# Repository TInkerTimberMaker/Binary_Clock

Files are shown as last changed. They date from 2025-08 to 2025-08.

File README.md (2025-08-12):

# Arduino Binary Clock (3× 74HC595 + DS3231)

A friendly, buildable binary‑coded decimal (BCD) clock for the Arduino Nano. It drives **three chained 74HC595 shift registers** in **sink mode** to show **hours, minutes, seconds**. A **DS3231 RTC** provides accurate timekeeping; two buttons set the time; a pot on **A1** controls global brightness via PWM on **D6**.

---
## Features
- **Time display**: Shows hours (00–23), minutes (00–59), seconds (00–59)
- **Accurate time** via DS3231 RTC (±2 ppm typical)
- **Packed BCD display**: tens and ones shown separately for Hours, Minutes, and Seconds
- **Brightness knob**: analog pot (A1) → PWM on OĒ (D6)
- **Set time**: Two buttons increment **minutes (D4)** and **hours (D3)**
- **Startup animation** if the RTC reports lost power (until a button press)
- **Low overhead**: loop updates only when the second changes; prints `HH:MM:SS  — CPU Work: xxxxµs` over Serial @ 9600 baud
- **Serial debug**: Prints `HH:MM:SS` on USB serial at 9600 baud

---
## Hardware Required
- Arduino Nano (or any 5 V Arduino)
- 3 × 74HC595N shift‑register chips
- DS3231 RTC module
- LEDs × 20 (6 hr + 7 min + 7 sec)
- Resistors (~470 Ω) × 20
- 1000µF electrolytic cap
- 2 × momentary pushbuttons
- Breadboard/wiring, Perfboard and hook up wires, or PCB

> **Sink mode** means LED anodes go to **+5 V** through a resistor and the HC595 outputs **pull low** to light the LED. That’s why the sketch inverts the BCD bits.

---
## Wiring

### Arduino ↔ 74HC595 chain

**Chain the data:** Arduino drives the **first** HC595’s SER; then **Q7′ (pin 9)** of each chip feeds the **next** chip’s SER.

| Connection | HC595 #1 | HC595 #2 | HC595 #3 |
| --- | --- | --- | --- |
| **D11 → SER (data)** | Pin 14 | *(from #1 Q7′ pin 9 → #2 SER pin 14)* | *(from #2 Q7′ pin 9 → #3 SER pin 14)* |
| **D12 → SH\_CP (shift clock)** | Pin 11 | Pin 11 | Pin 11 |
| **D8  → ST\_CP (latch)** | Pin 12 | Pin 12 | Pin 12 |
| **D6  → OĒ (PWM brightness)** | Pin 13 | Pin 13 | Pin 13 |
| **+5 V → SRCLR̄** | Pin 10 | Pin 10 | Pin 10 |
| **+5 V / GND** | Pin 16 / Pin 8 | Pin 16 / Pin 8 | Pin 16 / Pin 8 |

> If you don’t need brightness control, you may tie **OĒ (pin 13) to GND**. With dimming, keep OĒ on **D6 (PWM)**.

### RTC (DS3231)

| RTC Pin | Arduino |
| --- | --- |
| VCC | +3.3 V |
| GND | GND |
| SDA | A4 |
| SCL | A5 |
| SQW | *(optional)* D2 (for 1 Hz interrupt; not required in this sketch) |

### LED mapping (sink‑mode)

Each LED: **+5 V → resistor → LED anode → LED cathode → Qx** on the HC595.

- **Seconds** (HC595 #1):
  - Ones: Q0 (1), Q1 (2), Q2 (4), Q3 (8)
  - Tens: Q4 (10), Q5 (20), Q6 (40)
- **Minutes** (HC595 #2): same bit layout as seconds
- **Hours**   (HC595 #3):
  - Ones: Q0 (1), Q1 (2), Q2 (4), Q3 (8)
  - Tens: Q4 (10)

> Bits Q7 are unused in this layout; you can repurpose them for a colon or status LED.

### Buttons (active‑LOW using internal pull‑ups)

| Arduino | Function  |
| --- | --- |
| D4 | Minutes ↑ |
| D3 | Hours ↑ |

Wire one side of each button to the Arduino pin above, the other side to **GND**.

---
## Software

- **IDE:** Arduino IDE (or Arduino CLI)
- **Libraries:** `RTClib` (Adafruit) — install via **Library Manager**

### Upload

1. Open the sketch in the IDE.
2. Select **Board: Arduino Nano** and the correct **Port**.
3. `Tools → Processor` → choose your Nano’s bootloader if needed (Old/New).
4. Upload. Open **Serial Monitor** @ 9600 baud to see time + CPU microseconds.

### How it works

- The loop calls `rtc.now()` and **only updates the LEDs when the second changes**.
- `packBCD()` converts decimal to packed BCD; the bytes are **inverted** because 0 = LED ON in sink mode.
- Data are shifted **MSBFIRST**: seconds → minutes → hours; latch toggles once per update.
- Pressing the buttons constructs a new `DateTime` with the hour/minute incremented and writes it back with `rtc.adjust()`.
- `updateBrightness()` reads A1 and PWM‑drives OĒ on D6 to dim the whole display.

---

## Examples

At **00:00:00** (all off):

```
Sec  tens: 000
Sec  ones: 0000
Min  tens: 000
Min  ones: 0000
Hour tens: 0
Hour ones: 0000
```

At **12:34:56**:

```
Seconds: tens=5 → Q5+Q4  | ones=6 → Q2+Q1
Minutes: tens=3 → Q5+Q4  | ones=4 → Q2
Hours:   tens=1 → Q4     | ones=2 → Q1
```

At **23:59:59**:

```
Seconds: tens=5 → Q5+Q4  | ones=9 → Q3+Q0
Minutes: tens=5 → Q5+Q4  | ones=9 → Q3+Q0
Hours:   tens=2 → Q4+Q?* | ones=3 → Q1+Q0
```

\*Note: hours tens never exceeds 2; only Q4 (10) will typically be used. If you wire extra bits for hours tens, leave them unconnected or ignore them.

---

## Troubleshooting

- **All LEDs on:** OĒ (pin 13) stuck HIGH or not connected; in sink mode, remember the sketch inverts bits.
- **Nothing updates:** Check **D11/D12/D8** and the Q7′ chaining (pin 9 → next SER pin 14).
- **Random flicker:** Add decouplers (0.1 µF per HC595) + a bulk cap (220-1000 µF) on 5 V.
- **Wrong digit order:** Verify you kept **MSBFIRST** and the LED bit mapping matches your panel.
- **Time won’t hold:** Make sure the RTC’s **CR2032** battery is installed; if the RTC lost power the sketch will show the startup animation until a button press.

---

## Optional: 1 Hz interrupt

You can wire DS3231 **SQW → D2** and attach an interrupt to update the display exactly on each rising/falling edge. It’s not required (the sketch polls `rtc.now()`), but it can reduce I²C traffic and jitter.  This is not implemented in this code.

---

## License

**© 2025 Tinker & Timber** — This project is licensed under **CC BY‑SA 4.0** and provided **“as‑is”** without warranty. You may copy, modify, and redistribute under the same terms, provided this notice remains intact.

[https://creativecommons.org/licenses/by-sa/4.0/](https://creativecommons.org/licenses/by-sa/4.0/)

---

Made with ♥ by Tinker & Timber

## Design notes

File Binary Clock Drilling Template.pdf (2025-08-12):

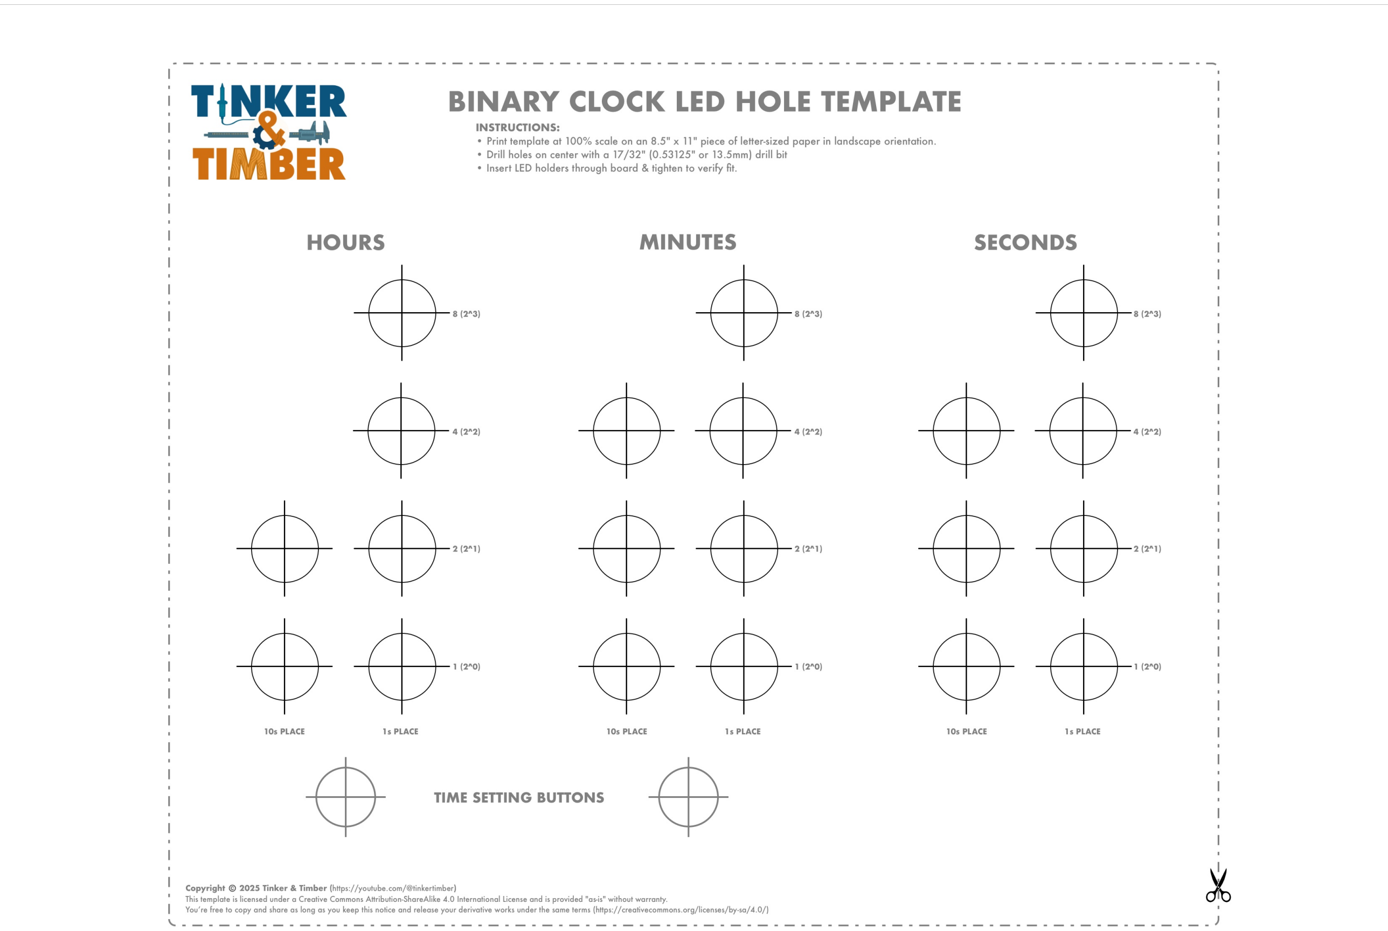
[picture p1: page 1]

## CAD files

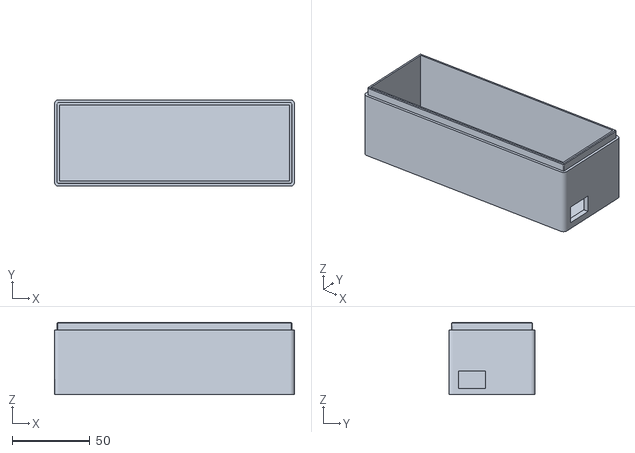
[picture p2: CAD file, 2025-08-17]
Binary Clock Case Full Box.stl
154.7 x 55.7 x 46.6

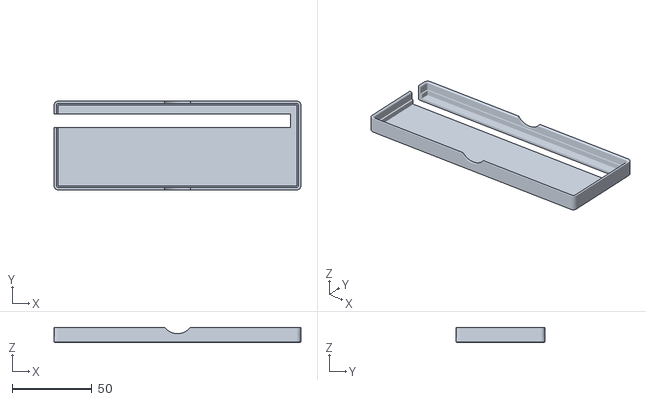
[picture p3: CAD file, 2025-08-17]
Binary Clock Case Full Lid.stl
154.7 x 55.7 x 9.60

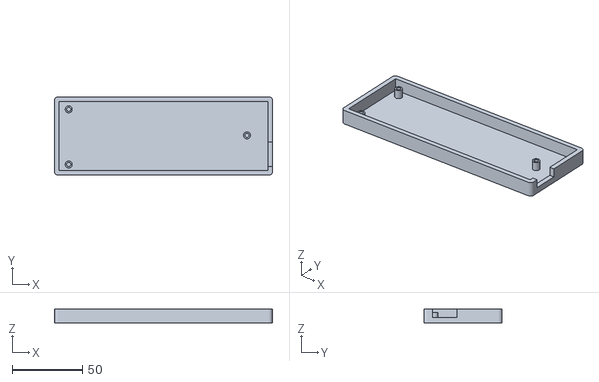
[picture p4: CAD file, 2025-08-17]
Binary Clock Case Minimal.stl
154.7 x 55.7 x 10.00

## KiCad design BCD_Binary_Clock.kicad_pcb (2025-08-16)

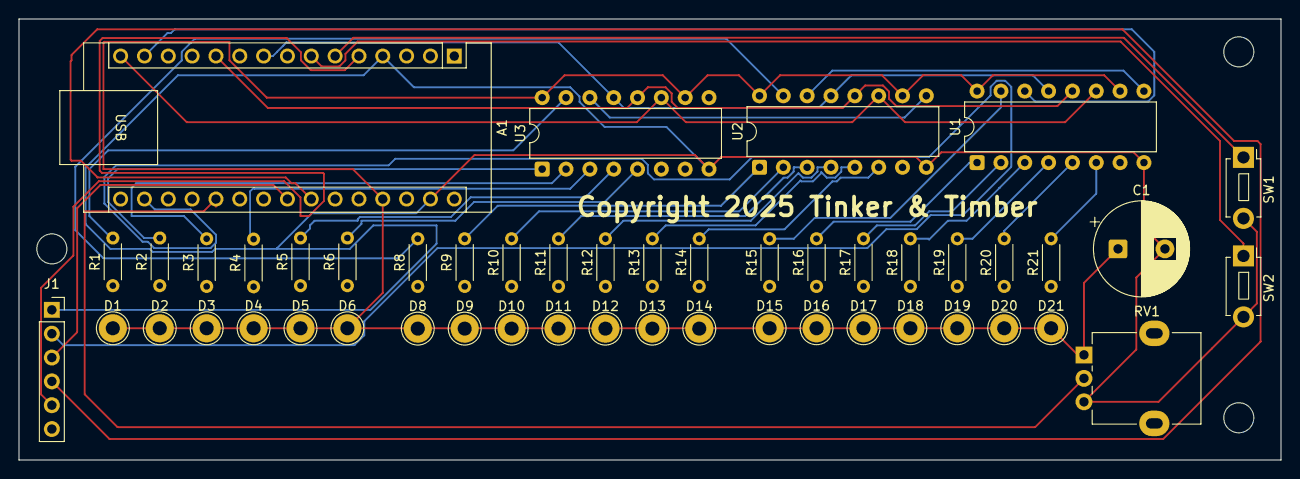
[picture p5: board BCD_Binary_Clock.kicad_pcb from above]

Board: 2 copper layers, 134.5 x 47.0 mm, 52 parts (0 on the bottom side), 35 nets.

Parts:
A1: Arduino Nano; Arduino_Nano
C1: 1000uF; CP_Radial_D10.0mm_P5.00mm
D1, D2, D3, D4, D5, D6, D8, D9, D10, D11, D12, D13, D14, D15, D16, D17, D18, D19, D20, D21: LED; TestPoint_THTPad_D3.0mm_Drill1.5mm
J1: PinSocket_1x06_P2.54mm_Vertical
Mount: MountingHole_3.2mm_M3
Mount#2, Mount#3: MountingHole_3.2mm_M3
R1, R2, R3, R4, R5, R6, R8, R9, R10, R11, R12, R13, R14, R15, R16, R17, R18, R19, R20, R21: 470Ω; R_Axial_DIN0204_L3.6mm_D1.6mm_P5.08mm_Horizontal
RV1: Brightness Pot; Potentiometer_Alpha_RD901F-40-00D_Single_Vertical
SW1: HRS BUTTON; SW_PUSH_1P1T_6x3.5mm_H4.3_APEM_MJTP1243
SW2: MIN BUTTON; SW_PUSH_1P1T_6x3.5mm_H4.3_APEM_MJTP1243
U1, U2, U3: 74HC595; DIP-16_W7.62mm

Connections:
GND: A1.4 (GND), A1.29 (GND), C1.2, J1.1, RV1.3, SW1.2, SW2.2, U1.8 (GND), U2.8 (GND), U3.8 (GND)
unnamed: A1.17 (3V3), J1.2
unnamed: A1.20 (A1), RV1.2
unnamed: A1.23 (A4), J1.3
unnamed: A1.24 (A5), J1.4
unnamed: A1.5 (D2), J1.5
unnamed: A1.6 (D3), SW1.1
unnamed: A1.7 (D4), SW2.1
unnamed: A1.9 (D6), U1.13 (~OE), U2.13 (~OE), U3.13 (~OE)
unnamed: A1.11 (D8), U1.12 (RCLK), U2.12 (RCLK), U3.12 (RCLK)
unnamed: A1.14 (D11), U1.14 (SER)
unnamed: A1.15 (D12), U1.11 (SRCLK), U2.11 (SRCLK), U3.11 (SRCLK)
unnamed: R15.2, U1.15 (QA)
unnamed: R16.2, U1.1 (QB)
unnamed: R17.2, U1.2 (QC)
unnamed: R18.2, U1.3 (QD)
unnamed: R19.2, U1.4 (QE)
unnamed: R20.2, U1.5 (QF)
unnamed: R21.2, U1.6 (QG)
unnamed: U1.9 (QH'), U2.14 (SER)
unnamed: R8.2, U2.15 (QA)
unnamed: R9.2, U2.1 (QB)
unnamed: R10.2, U2.2 (QC)
unnamed: R11.2, U2.3 (QD)
unnamed: R12.2, U2.4 (QE)
unnamed: R13.2, U2.5 (QF)
unnamed: R14.2, U2.6 (QG)
unnamed: U2.9 (QH'), U3.14 (SER)
unnamed: R1.2, U3.15 (QA)
unnamed: R2.2, U3.1 (QB)
unnamed: R3.2, U3.2 (QC)
unnamed: R4.2, U3.3 (QD)
unnamed: R5.2, U3.4 (QE)
unnamed: R6.2, U3.5 (QF)
VCC: A1.27 (+5V), C1.1, D1.1 (K), D2.1 (K), D3.1 (K), D4.1 (K), D5.1 (K), D6.1 (K), D8.1 (K), D9.1 (K), D10.1 (K), D11.1 (K), D12.1 (K), D13.1 (K), D14.1 (K), D15.1 (K), D16.1 (K), D17.1 (K), D18.1 (K), D19.1 (K), D20.1 (K), D21.1 (K), RV1.1, U1.10 (~SRCLR), U1.16 (VCC), U2.10 (~SRCLR), U2.16 (VCC), U3.10 (~SRCLR), U3.16 (VCC)

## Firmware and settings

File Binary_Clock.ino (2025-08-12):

/**
 * Binary Clock using 3×74HC595 Shift Registers
 *
 * - Displays hours (00–23), minutes (00–59), seconds (00–59) in packed BCD on LEDs.
 * - Uses three daisy-chained 74HC595N shift registers in sink-mode.
 * - Time source = DS3231 RTC via I²C (A4=SDA, A5=SCL) for ±2 ppm accuracy
 * - Two buttons (D4, D3) increment minutes and hours when pressed.
 * - Brightness control via PWM on D6 (OĒ) driven by pot on A1
 * - On first power-up (or if RTC lost power), runs a startup-sweep animation until time is set
 * - Each loop polls `rtc.now()`, updates display on second change
 * - Measures per-loop CPU/I²C overhead with `micros()` and prints “HH:MM:SS  – CPU: xxxx µs” over Serial @ 9600 baud
 *
 * Copyright 2025 - Tinker & Timber 
 * This code is licensed under the Creative Commons Attribution-ShareAlike 
 * 4.0 International (CC BY-SA 4.0) license and provided "as-is" without 
 * warranty. You are free to copy, modify, and redistribute under the same 
 * terms, provided this notice remains intact. https://creativecommons.org/licenses/by-sa/4.0/
 * 
 */

// --- Library Includes & Globals ------------------------------
#include <Arduino.h>
#include <Wire.h>
#include <RTClib.h>

RTC_DS3231 rtc;

// --- Hardware Pin Definitions  -------------------------------
// 74HC595N pins
constexpr   uint8_t SER_PIN       = 11;     // DS
constexpr   uint8_t SRCLK_PIN     = 12;     // SH_CP
constexpr   uint8_t RCLK_PIN      = 8;      // ST_CP
// DS3231 RTC Module
constexpr   uint8_t SDA_PIN       = A4;     // SDA (I²C pins, auto-handled by Wire.h, named for documentation)
constexpr   uint8_t SCL_PIN       = A5;     // SCL (I²C pins, auto-handled by Wire.h, named for documentation)
// Brightness control
constexpr   uint8_t OE_PWM_PIN    = 6;      // PWM → OĒ on 74HC595Ns
constexpr   uint8_t POT_PIN       = A1;     // pot wiper → analog input

// --- Button & Timing Constants -------------------------------
constexpr   uint8_t MIN_BTN_PIN   = 4;      // increment minutes pin
constexpr   uint8_t HR_BTN_PIN    = 3;      // increment hours pin - TODO! set back to pin #3 for printed PCB
constexpr   uint16_t DEBOUNCE     = 50;     // in ms
uint32_t    lastMinPress          = 0, 
            lastHrPress           = 0;
bool        minPressed            = false;
bool        hrPressed             = false;
bool        timeSet               = false;  // time not set on power on 
uint8_t     lastSecond            = 255;    // only redraw on change
uint32_t    lastOverheadUs        = 0;      // used to measure µproc work

// --- Forward‐declared functions ------------------------------
void writeClock(uint8_t hr, uint8_t mn, uint8_t sc);
void printTime(const DateTime &now);
void startupSweep();
void updateBrightness();
void writeRaw(uint32_t mask);

// =============================================================================
// SETUP LOOP
// =============================================================================
void setup() {

// Enable serial output 
  Serial.begin(9600);

// Output to clock shift registers
  pinMode(SER_PIN, OUTPUT);
  pinMode(SRCLK_PIN, OUTPUT);
  pinMode(RCLK_PIN, OUTPUT);

// Input buttons (for setting time)
  pinMode(MIN_BTN_PIN, INPUT_PULLUP);
  pinMode(HR_BTN_PIN, INPUT_PULLUP);

// Output PWM for display brightness
  pinMode(OE_PWM_PIN, OUTPUT);

// RTC Module Setup
if (!rtc.begin()) {
    Serial.println("Couldn't find RTC");
    while (1);
  }
  // if module lost power, show startup animation
  if (rtc.lostPower()) {
    Serial.println(F("RTC lost power, running startup animation!"));
    startupSweep();
  } else {
    timeSet = true;
    DateTime now = rtc.now();
    writeClock(now.hour(), now.minute(), now.second());
    printTime(now);
  }
}

// =============================================================================
// MAIN LOOP
// =============================================================================
void loop() {
  uint32_t loopStart = micros();    // start timing for µProc work
  uint32_t ms = millis();           // set millis for switch debouncing
  DateTime now = rtc.now();         // get time from the RTC

  if (!timeSet) return;             // through setup(), should be flipped and not showing default animation

  updateBrightness();               // Set brightness of the display

// Read raw state (active LOW)
  bool minState = (digitalRead(MIN_BTN_PIN) == LOW);
  bool hrState = (digitalRead(HR_BTN_PIN) == LOW);

// MINUTE button: detect LOW → HIGH transition (pressed once)
  if (minState && !minPressed && ms - lastMinPress > DEBOUNCE) {
    minPressed   = true;
    lastMinPress = ms;

    uint8_t newMin = (now.minute() + 1) % 60;
    DateTime shifted(
      now.year(), now.month(), now.day(),
      now.hour(), newMin, now.second()
    );
    rtc.adjust(shifted);  // write new time back into the DS3231
    writeClock(shifted.hour(),
               shifted.minute(),
               shifted.second());
    printTime(now);
  }
  if (!minState && minPressed) minPressed = false;

// HOUR button: detect LOW → HIGH transition (pressed once)
  if (hrState && !hrPressed && ms - lastHrPress > DEBOUNCE) {
    hrPressed    = true;
    lastHrPress  = ms;

    uint8_t newHr = (now.hour() + 1) % 24;
    DateTime shifted(
      now.year(), now.month(), now.day(),
      newHr, now.minute(), now.second()
    );
    rtc.adjust(shifted);  // write new time back into the DS3231
    writeClock(shifted.hour(),
               shifted.minute(),
               shifted.second());
    printTime(now);
  }
  if (!hrState && hrPressed) hrPressed = false;

  // only update display when second rolls over
  if (now.second() != lastSecond) {
    lastSecond = now.second();
    if (!timeSet) timeSet = true; 

    // get hours, minutes, seconds from RTC & update display
    writeClock(now.hour(), now.minute(), now.second());
    printTime(now);
  }

  lastOverheadUs = micros() - loopStart;    // capture the work time in µs
  delay(10);                                // small delay to avoid hammering the I2C bus
}

// -----------------------------------------------------------------------------
// ——— Display "animation" on startup when time is not set ——— 
// -----------------------------------------------------------------------------
void startupSweep() {
  // Nibble positions 0…3 corresponding to bit-pairs {0,4},{1,5},{2,6},{3,7}
  constexpr uint8_t STEPS[] = { 0, 1, 2, 3, 2, 1 };

  // keep running until a button press flips timeSet = true
  while (!timeSet) {
    for (uint8_t p : STEPS) {
      uint8_t nibble = ~((1 << p) | (1 << (p + 4)));  // Build one‐byte pattern: bits p and (p+4)

      // Replicate that byte into a 24-bit mask for the three chained registers
      uint32_t mask = (uint32_t(nibble) << 16)
                    | (uint32_t(nibble) <<  8)
                    |  uint32_t(nibble);
      writeRaw(mask);
      Serial.println("~~~ Time Not Set ~~~");

      // pause up to 200 ms, but break immediately on any button
      for (uint32_t t = 0; t < 200; t += 50) {
        delay(50);
        // Set brightness of the display
        updateBrightness();               
        if (digitalRead(MIN_BTN_PIN) == LOW ||
            digitalRead(HR_BTN_PIN)  == LOW) {
          timeSet = true;
          return;
        }
      }
    }
  }
}

// ——— Convert decimal values into a BCD packed format ———
// -----------------------------------------------------------------------------
static inline uint8_t packBCD(uint8_t v) {
  return uint8_t((v / 10) << 4) | (v % 10);   // high nibble = tens digit, low nibble = ones digit
}

// ——— Shift data to 74HC595N registers ———
// -----------------------------------------------------------------------------
void writeClock(uint8_t hr, uint8_t mn, uint8_t sc) {
// 1st byte (secs) → HC595 #1 | 2nd byte (mins) → HC595 #2 | 3rd byte (hrs)  → HC595 #3

// Convert decimal values to packed BCD format
  uint8_t hrBCD = packBCD(hr),
          mnBCD = packBCD(mn),
          scBCD = packBCD(sc);

// Invert for sinking current (0 = LED on)
  hrBCD = ~hrBCD;
  mnBCD = ~mnBCD;
  scBCD = ~scBCD;

// Shift data out to 74HC595Ns
  digitalWrite(RCLK_PIN, LOW);
  shiftOut(SER_PIN, SRCLK_PIN, MSBFIRST, hrBCD);
  shiftOut(SER_PIN, SRCLK_PIN, MSBFIRST, mnBCD);
  shiftOut(SER_PIN, SRCLK_PIN, MSBFIRST, scBCD);
  digitalWrite(RCLK_PIN, HIGH);
}

// ——— Set brightness of entire display ———
// -----------------------------------------------------------------------------
void updateBrightness() {
  uint8_t bright = map(analogRead(POT_PIN), 0, 1023, 0, 255);   // get value from pot
  analogWrite(OE_PWM_PIN, 255 - bright);                        // set duty cycle on OĒ for the 75HC595Ns  
  //Serial.println(bright);
}

// ——— Write a raw 24-bit mask to the three shift registers ——— 
// -----------------------------------------------------------------------------
static void writeRaw(uint32_t mask) {
  digitalWrite(RCLK_PIN, LOW);
    shiftOut(SER_PIN, SRCLK_PIN, MSBFIRST, (mask >> 16) & 0xFF);
    shiftOut(SER_PIN, SRCLK_PIN, MSBFIRST, (mask >>  8) & 0xFF);
    shiftOut(SER_PIN, SRCLK_PIN, MSBFIRST,  mask        & 0xFF);
  digitalWrite(RCLK_PIN, HIGH);
}

// ——— Print current time & µProc work to the serial interface ———
// -----------------------------------------------------------------------------
void printTime(const DateTime &now) {
  char buf[48];
  snprintf(buf, sizeof(buf),
    "Current Time: %02u:%02u:%02u  -- CPU Work: %4luµs",
    now.hour(), now.minute(), now.second(),
    lastOverheadUs);
  Serial.println(buf);
}

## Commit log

2025-08-12 Drilling Template for LED panel
2025-08-12 PCB Gerber Files
    Use to get your own PCBs made
2025-08-12 KiCAD Circuit Schematic
    [BCD_Binary_Clock.kicad_sch]
2025-08-12 KiCAD PCB Layout
    [BCD_Binary_Clock.kicad_pcb]
2025-08-12 Binary Clock Arduino Code v1.0
2025-08-16 Fixed SW1 & SW2 going to VCC - now pulling to GNC
    [BCD_Binary_Clock.kicad_pcb]
2025-08-17 Added STLs for case (full & minimal versions)
    [Binary Clock Case Full Box.stl, Binary Clock Case Full Lid.stl, Binary Clock Case Minimal.stl]
2025-08-19 Updated Gerbers to pull switches to GND not VCC
